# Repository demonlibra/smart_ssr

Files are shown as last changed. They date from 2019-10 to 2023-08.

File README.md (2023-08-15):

# Умное твердотельное реле с анализом ШИМ

### Ссылки
- [Обсуждение в теме форума UNI](https://forum.uni-3d.ru/viewtopic.php?t=527)
- [Как залить Sketch в Arduino?](https://alexgyver.ru/arduino-first)

### Описание проблемы
Твердотельное реле Zero-Cross в процессе работы пропустит только те полупериоды синусоидального напряжения питания, начало которых совпадёт с импульсами сигнала ШИМ от платы управления. В результате твердотельное реле может находится в трёх состояниях: закрыто, открыто и открыто для одного полупериода. Так как между сетевым напряжением и управляющим сигналом ШИМ всегда будет "плавающая" рассинхронизация, можно говорить лишь о вероятности одного из этих состояний.

Например, при частоте питающего напряжения равной частоте ШИМ сигнала управления (50 Гц) и коэффициенте заполнения сигнала управления отличным от 1.0, можно говорить лишь о вероятности одного из трех состояний твердотельного реле.
- Коэффициент заполнения = 1.0 - полная мощность
- Коэффициент заполнения ≥ 0.5 - половина или полная мощность
- Коэффициент заполнения < 0.5 - 0 или половина мощности

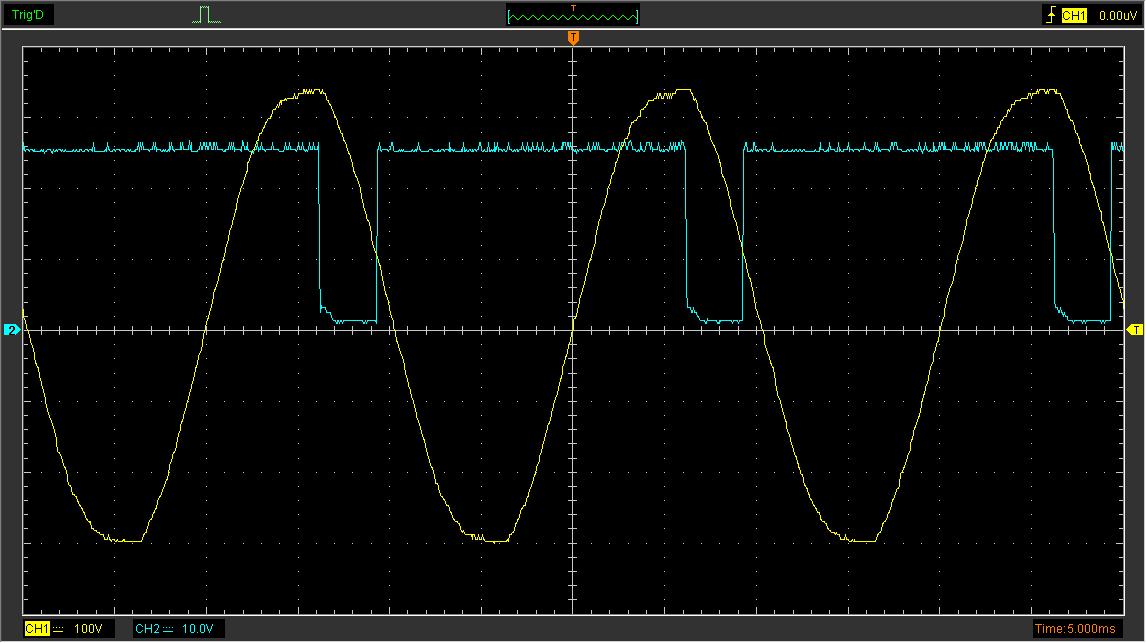
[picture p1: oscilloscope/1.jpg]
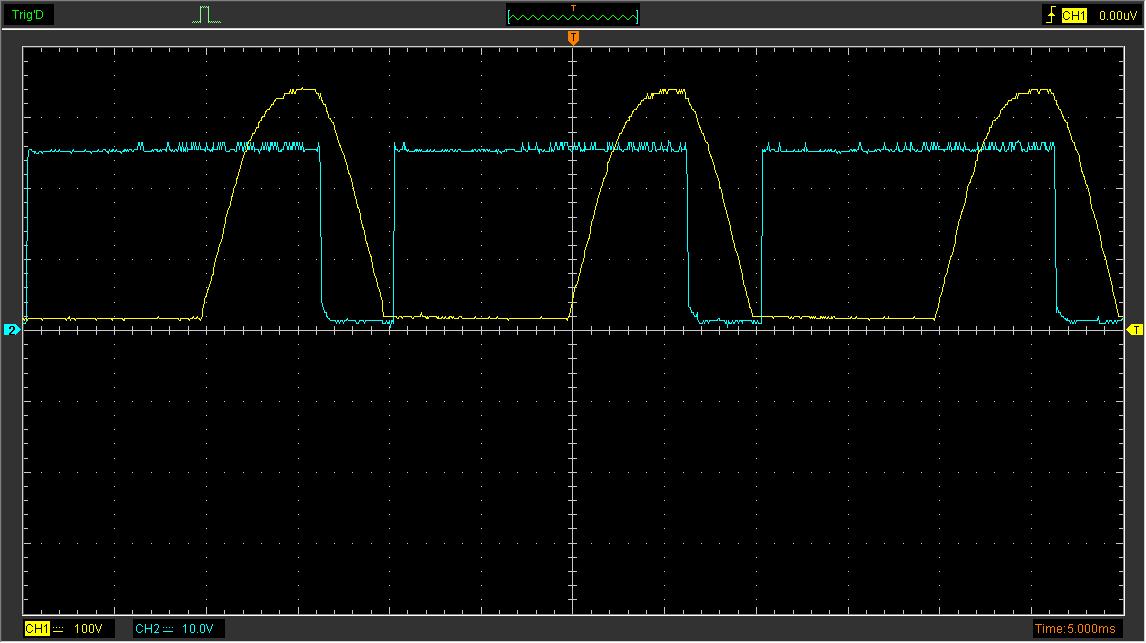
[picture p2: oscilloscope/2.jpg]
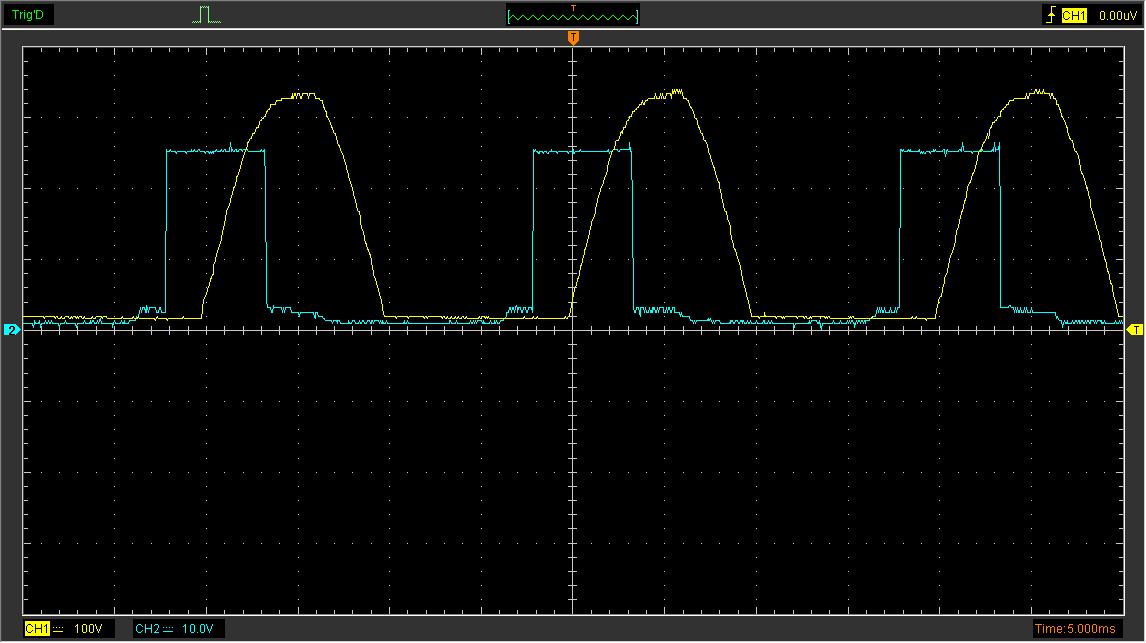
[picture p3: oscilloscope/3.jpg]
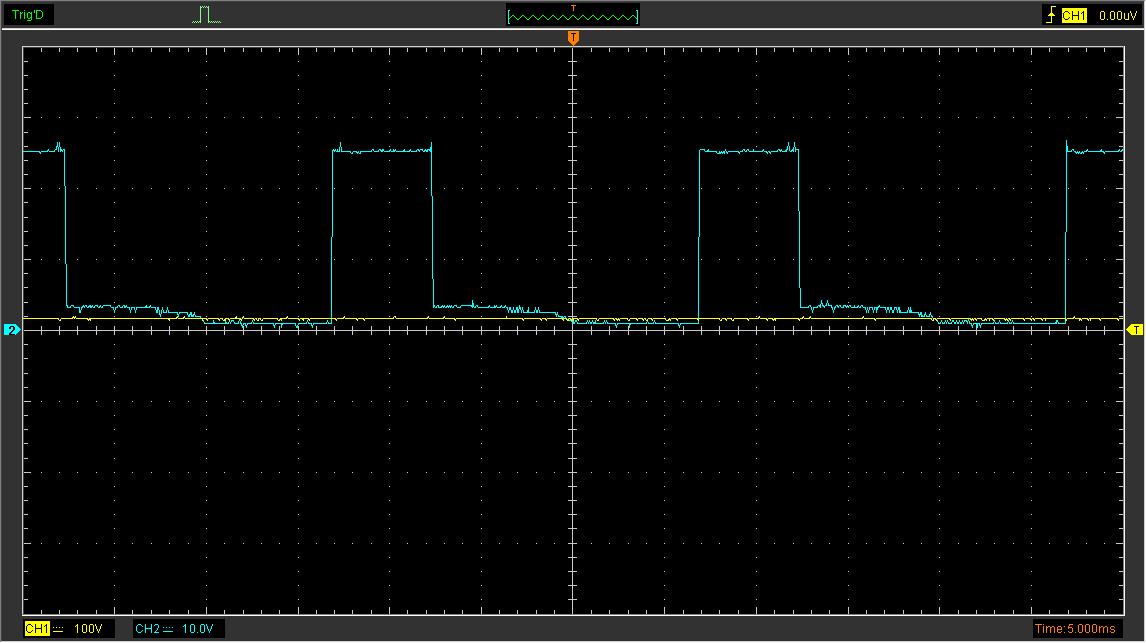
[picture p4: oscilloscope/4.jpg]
   

Снимки 1 и 2 - Коэффициент заполнения ШИМ управляющего сигнала (синий) одинаковый, но мощность на выходе (жёлтый) будет отличаться в два раза.  
Снимки 2 и 3 - Коэффициент заполнения отличается в 4 раза, но мощность одинаковая.  
Снимки 3 и 4 - Коэффициент заполнения одинаковый, но мощность разная.  

Несоответствие коэффициента заполнения ШИМ сигнала управления и выходной мощности может быть причиной больших отклонений температуры от заданной. 
Решить описанную проблему может следующее решение:

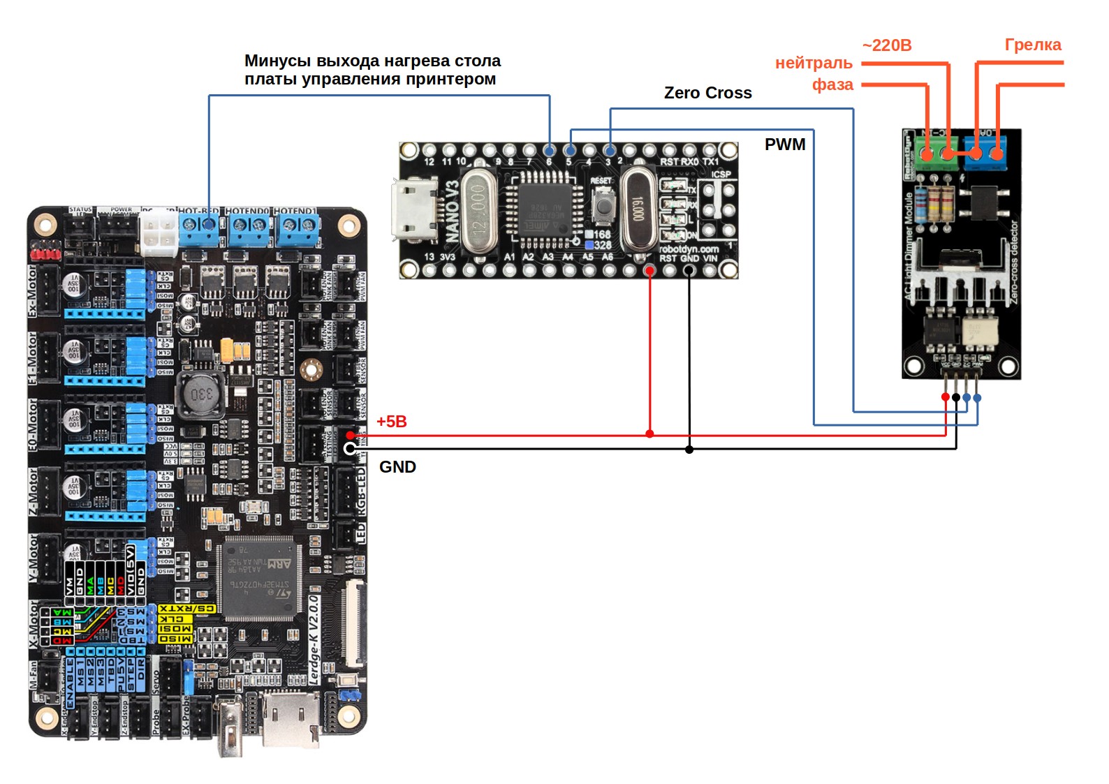
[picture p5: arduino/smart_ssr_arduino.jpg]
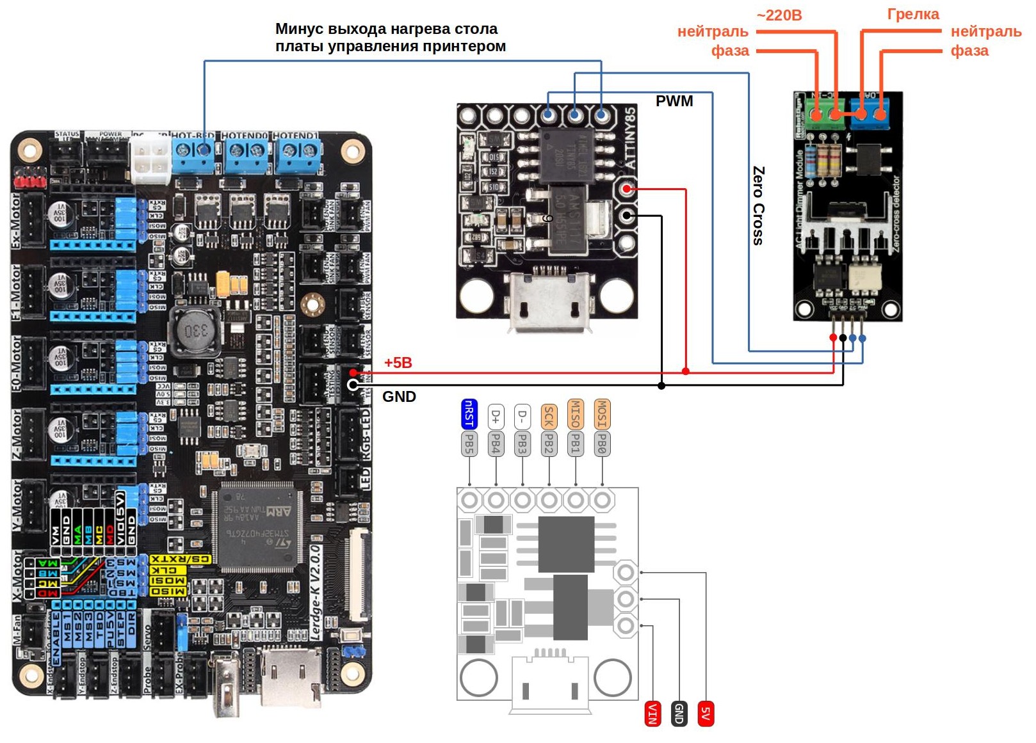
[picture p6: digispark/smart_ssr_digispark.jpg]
 

### Комплектующие
- Arduino или digispark
- [Димер от Robotdyn](https://robotdyn.aliexpress.ru/store/1950989/search?origin=n&SortType=new_desc&SearchText=dimmer)

### Принцип работы
1. Сигнал управления поступает на вход Arduino, которая определяет длительность импульсов включения и коэффициент заполнения ШИМ.
2. Димер подаёт на Arduino сигналы перехода синусоиды напряжения через 0 для определения моментов времени открытия симистора. Таким образом достигается синхронизация сигнала управления и сетевого напряжения.
3. Сетевое напряжение с частотой 50 Гц имеет 100 полупериодов за одну секунду. Arduino выдаёт сигналы управления на димер для получения необходимой мощности, пропуская в единицу времени часть полупериодов сетевого напряжения. Таким образом достигается дискретность задания мощности 1%. Например, если за секунду пропустить только 20 полупериодов, будет получено 20% мощности.

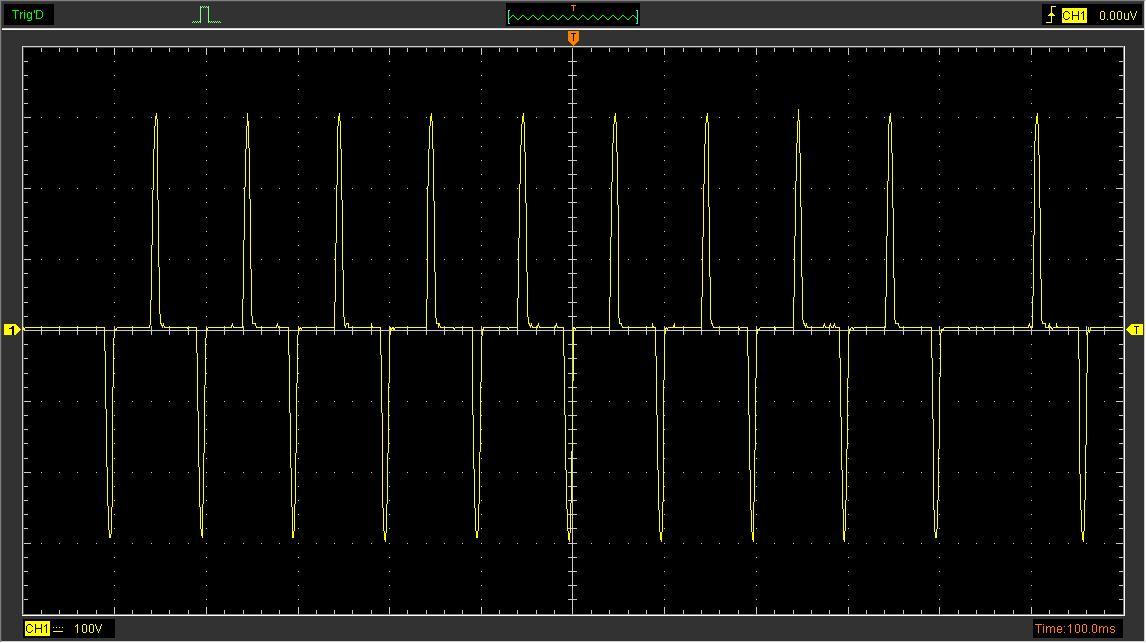
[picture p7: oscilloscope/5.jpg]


Данное решение позволяет устранить проблемы неадекватной работы нагревателя с обычным твердотельным реле:
- Устранить проблему невозможности автоматической калибровки параметров ПИД.
- Обеспечить более точное поддержание температуры.
- Задать ограничение мощности. Может быть актуально для мощных грелок, если стол искривляется от быстрого нагрева.

### Важно
У большинства всё работает и без этого велосипеда. Не торопитесь реализовывать данную схему.
В большинстве случаев проблема управления твердотельным реле решается понижением частоты ШИМ меньше 10 Гц.

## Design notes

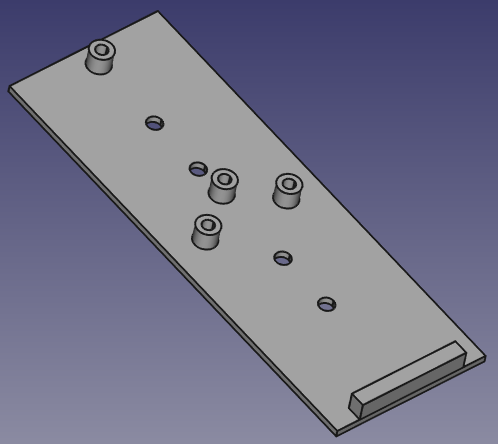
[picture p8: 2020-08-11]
arduino/smart_ssr_arduino.png

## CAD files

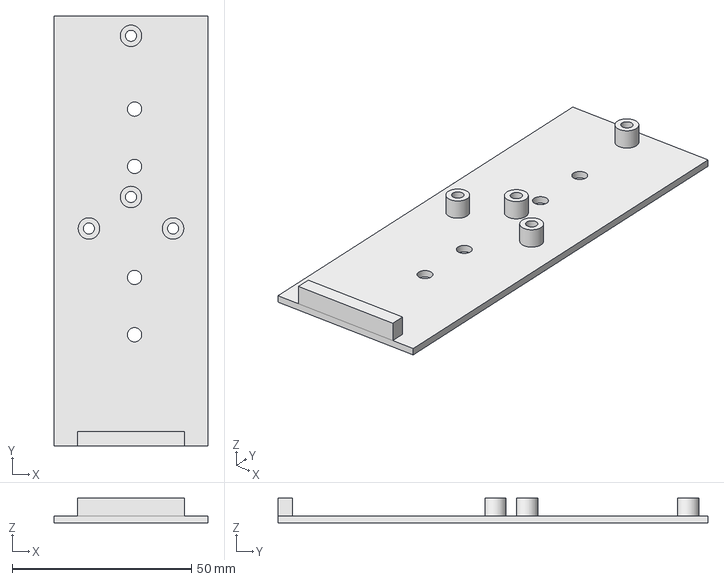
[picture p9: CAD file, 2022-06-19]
arduino/smart_ssr_arduino.step
43.0 x 120.0 x 6.85 mm

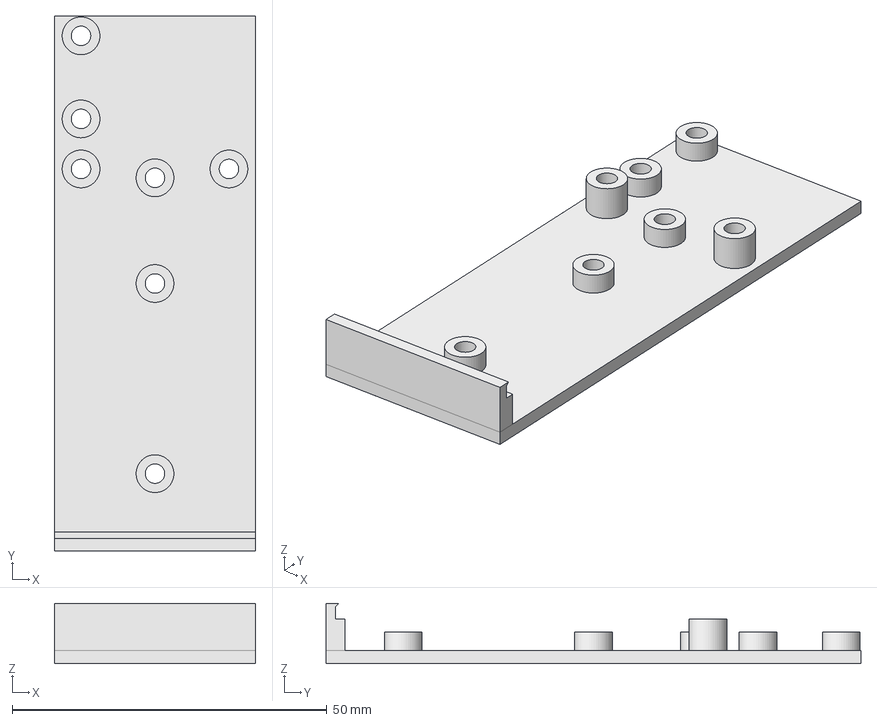
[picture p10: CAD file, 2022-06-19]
digispark/smart_ssr_digispark.step
32.0 x 85.0 x 9.55 mm

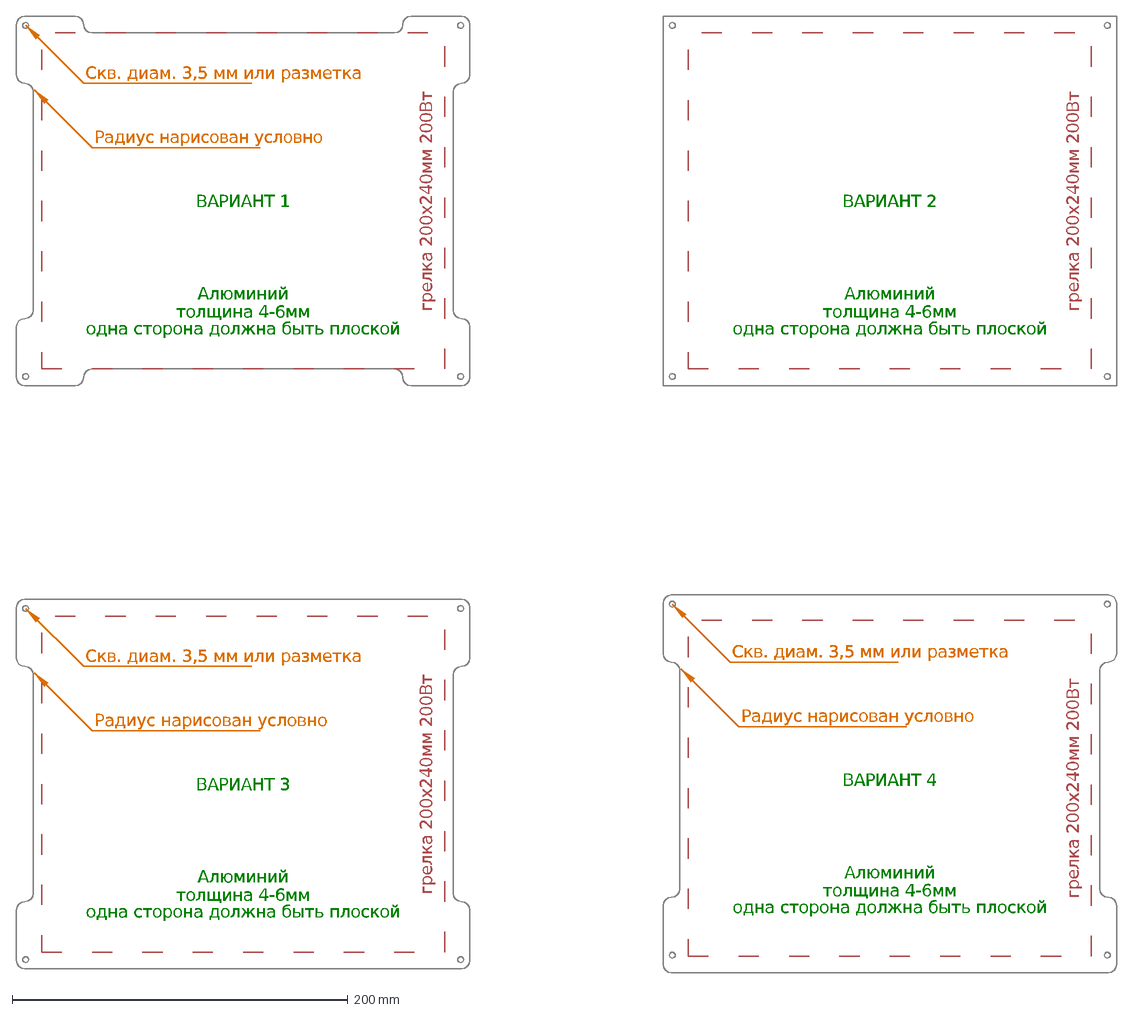
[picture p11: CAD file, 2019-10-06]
Плита стола 220x270.dxf
Cкв. диам. 3,5 мм или разметка
Скв. диам. 3,5 мм или разметка
Радиус нарисован условно
грелка 200х240мм 200Вт
Алюминий
толщина 4-6мм
одна сторона должна быть плоской
ВАРИАНТ 1
ВАРИАНТ 2
ВАРИАНТ 3
ВАРИАНТ 4

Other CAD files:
arduino/dimmer+arduino.step
arduino/smart_ssr_arduino.FCStd
arduino/smart_ssr_arduino.stl
digispark/smart_ssr_digispark.FCStd
digispark/smart_ssr_digispark.stl

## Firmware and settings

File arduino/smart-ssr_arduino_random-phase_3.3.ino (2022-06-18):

// Умное твердотельное реле или Питание грелки без потери ШИМ
// Версия 3.3 для Arduino от 14/08/2020
// Вариант Random-Phase 
// http://uni3d.store/viewtopic.php?f=63&t=527
// https://github.com/demonlibra/uni/tree/master/smart_ssr


// ------------------ Проверьте параметры ниже ---------------------------------------------------------

unsigned int power_nominal = 600;     // Номинальная мощность грелки (Вт)
unsigned int power_limit   = 300;     // Ограничение максимальной мощности грелки (Вт)

const byte   freq_supply   = 50;      //  Частота напряжения в сети (Гц)
const byte   freq_pwm      = 50;      //  Частота ШИМ на выходе платы управления (Гц). Для Lerdge = 50, для Marlin = 8.

const byte   pwm_in        = 6;       // Вход ШИМ сигнала нагрева стола от платы управления принтером
const byte   ZC_in         = 3;       // Вход сигнала перехода синусоиды напряжения через ноль (Zero Cross)
const byte   dimmer_out    = 5;       // Выход управления димером (PWM)

// ------------------ Проверьте параметры выше ---------------------------------------------------------
// -----------------------------------------------------------------------------------------------------


const unsigned int period_supply = 1 * 1000000 / freq_supply;   // Период (мкс) напряжения в сети
const unsigned int period_pwm    = 1 * 1000000 / freq_pwm;      // Период (мкс) ШИМ сигнала на выходе платы управления

unsigned int T = period_supply / 2;   // Задержка включения симистора

float duty_cycle_limit = (float)power_limit / power_nominal;    // Ограничение мощности

int duty = 0;                         // Длительность импульсов ШИМ от платы управления принтером
float duty_cycle;                     // Коэффициент заполнения ШИМ от платы управления принтером
float radian;

uint32_t Lerdge_PWM_Start = micros(); // Время начала импульса ШИМ от платы управления принтером
uint32_t Lerdge_PWM_End   = micros(); // Время окончание импульса ШИМ от пплаты управления принтером
uint32_t timer_ZC         = micros(); // Время перехода синусоиды напряжения через ноль

unsigned int ZC_duration  = 0;        // Длительность импульса определения перехода синусоиды напряжения через ноль

uint32_t timer_debug      = millis(); // Таймер вывода данных в терминал для отладки

bool Lerdge_PWM_state_Now = 1;
bool Lerdge_PWM_state_Before = 1;
bool ZC_before = 0;
bool ZC_now = 0;
bool pwm_out = 0;

void setup() {
  pinMode(pwm_in, INPUT_PULLUP);
  pinMode(ZC_in, INPUT_PULLUP);
  pinMode(dimmer_out, OUTPUT);
  //Serial.begin(9600);
}

void loop() {

  Lerdge_PWM_state_Now = digitalRead(pwm_in);               // Текущее состояние ШИМ

  if (!Lerdge_PWM_state_Now && Lerdge_PWM_state_Before) {
    Lerdge_PWM_Start = micros();                            // Определение фронта импульса ШИМ сигнала
  }
  if (Lerdge_PWM_state_Now && !Lerdge_PWM_state_Before) {
    Lerdge_PWM_End = micros();                              // Определение спада импульса ШИМ сигнала
    duty = Lerdge_PWM_End - Lerdge_PWM_Start;               // Расчёт длительности импульса ШИМ сигнала
  }

  if (!Lerdge_PWM_state_Now && (micros() - Lerdge_PWM_Start > period_pwm)) duty = period_pwm; // Если нет импульсов и коэффициент заполнения 100%
  if (Lerdge_PWM_state_Now && (micros() - Lerdge_PWM_End > period_pwm)) duty = 0;             // Если нет импульсов и коэффициент заполнения 0%
  if (duty < 0) duty = 0;

  duty_cycle = (float)duty / period_pwm;                    // Rоэффициент заполнения ШИМ = Длительность импульса / период (20000 мкс)
  if (duty_cycle > duty_cycle_limit) duty_cycle = duty_cycle_limit;   // Ограничение мощности

  Lerdge_PWM_state_Before = Lerdge_PWM_state_Now;           // Сохранение предыдущего состояния ШИМ


  // Расчет момента времени открытия симистора через пропорцию площади ШИМ и площади синусоиды:
  // ------------------------------------------------------------------------------------------
  //
  // Площадь полупериода синусоиды = 2
  // Необходимая площадь S = (Площадь полупериода синусоиды) х (Коэффициент заполнения) = duty_cycle x 2
  //
  // Площадь под аркой синусоиды S = cos(x1) - cos(x2)
  // Конец арки синусоиды совпадает с переходом через 0, т.е. x2 = Pi и cos(x2) = cos(Pi) = -1
  //
  // duty_cycle x 2 = cos(x1) - (-1)
  // cos(x1) = duty_cycle x 2 - 1
  // radian = acos(duty_cycle * 2 - 1);                         // !!! Вычисление занимает около ~270 мкс
  //
  // Pi     <=> 10000 мс
  // radian <=> T
  //
  // T = radian * period/2 / 3.1415;                              // Момент времени открытия симистора


  ZC_now = digitalRead(ZC_in);                                  // Текущее состояние триггера перехода напряжения через ноль

  if (ZC_now && !ZC_before) {                                   // Выполнять, если обнаружен фронт перехода напряжения через ноль
    pwm_out = 1;                                                // Триггер разрешения выдачи импульса открытия симистора
    timer_ZC = micros();                                        // Запись времени перехода напряжения через ноль
    radian = acos(duty_cycle * 2 - 1);
    T = radian * period_supply/2 / 3.1415;                      // Момент времени открытия симистора
  }

  if (!ZC_now && ZC_before) ZC_duration = micros() - timer_ZC;  // Расчет длительности импульса определения перехода фазы через ноль

  ZC_before = ZC_now;                                           // Сохранение текущего состояния

  // Активация симистора. Импульс необходимо выключить заблаговременно. Иначе спад импульса может оказаться после момент перехода фазы через ноль.
  if ((micros() - timer_ZC > T + ZC_duration/2) && pwm_out && (T < period_supply/2)) {
    digitalWrite(dimmer_out, HIGH);                             // Фронт импульса открытия симистора
    pwm_out = 0;                                                // Обнуление триггера для обеспечения выдачи короткого импульса
    digitalWrite(dimmer_out, LOW);                              // Спад импульса открытия симистора
  } else {
    digitalWrite(dimmer_out, LOW);                              // Контрольный спад импульса открытия симистора
  }

  // Вывод данных в терминал для отладки
  if (millis() - timer_debug > 1000 ) {
    //Serial.println("duty=" + String(duty) + " duty_cycle=" + String(duty_cycle) + " T=" + String(T));
    //Serial.println(duty_cycle);
    //Serial.println("period_supply=" + String(period_supply) + " period_pwm=" + String(period_pwm));
    timer_debug = millis();
  }
}

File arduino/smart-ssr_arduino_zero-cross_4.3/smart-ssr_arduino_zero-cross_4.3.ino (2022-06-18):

// Умное твердотельное реле (Smart-SSR) или "Питание грелки 220В без потери ШИМ"
// Sketch для Arduino
// Версия 4.3 от 05/09/2020
// Вариант Zero-Cross с равномерным распределением включений симистора
// Обсуждение: http://uni3d.store/viewtopic.php?f=63&t=527
// Файлы проекта: https://github.com/demonlibra/uni/tree/master/smart_ssr


// ------------------ Проверьте параметры ниже ---------------------------------------------------------

const uint16_t power_nominal = 600;   // Номинальная мощность грелки (Вт)
const uint16_t power_limit   = 350;   // Ограничение максимальной мощности грелки (Вт)

const byte   freq_supply   = 50;      //  Частота напряжения в сети (Гц)
const byte   freq_pwm      = 50;      //  Частота ШИМ на выходе платы управления (Гц). Для Lerdge = 50, для Marlin = 8.
const byte   update_pwm    = 1;       //  Периодичность изменения ШИМ на выходе платы управления (раз в секунды). Для Lerdge = 1, для Marlin = ???.

const byte   pwm_in        = 6;       // Вход ШИМ сигнала нагрева стола от платы управления принтером
const byte   ZC_in         = 3;       // Вход сигнала перехода синусоиды напряжения через ноль (Zero Cross)
const byte   dimmer_out    = 5;       // Выход управления димером (PWM)

// ------------------ Проверьте параметры выше ---------------------------------------------------------
// -----------------------------------------------------------------------------------------------------

const byte freq_supply_zc   = freq_supply * 2;                   // Количество полупериодов питающего напряжения
const uint32_t period_pwm   = 1000000 / freq_pwm;                // Период (мкс) ШИМ сигнала на выходе платы управления
const byte duty_cycle_limit = 100 * power_limit / power_nominal; // Ограничение мощности через коэффициент заполнения

uint32_t duty = 0;                    // Длительность импульсов ШИМ от платы управления принтером
byte duty_cycle = 0;                  // Расчётный коэффициент заполнения ШИМ от платы управления принтером

byte duty_cycle_count = 0;            // Счётчик полупериодов, которые нужно открыть
byte zc_count = freq_supply_zc;       // Счётчик переходов через ноль

byte skip = 0;                        // Пропуск полупериодов для равномерного распределения
byte skip_count = 0;                  // Счётчик пропуска полупериодов

uint32_t Lerdge_PWM_Start = micros(); // Время начала импульса ШИМ от платы управления принтером
uint32_t Lerdge_PWM_End   = micros(); // Время окончание импульса ШИМ от пплаты управления принтером
uint32_t timer_debug;                 // Таймер вывода данных в последовательный порт    

bool Lerdge_PWM_state_Now = 1;        // Текущее состояние сигнала ШИМ (сигнал инвертирован)
bool Lerdge_PWM_state_Before = 1;     // Предыдущее состояние сигнала ШИМ (сигнал инвертирован)
bool ZC_now = 0;                      // Текущее состояние сигнала Zero-Cross
bool ZC_before = 0;                   // Предыдущее состояние сигнала Zero-Cross

void setup() {
  pinMode(pwm_in, INPUT_PULLUP);      // Назначение входа для сигнала ШИМ от платы управления
  pinMode(ZC_in, INPUT_PULLUP);       // Назначение входа для сигнала Zero-Cross от димера
  pinMode(dimmer_out, OUTPUT);        // Назначение выхода управления димером

  //Serial.begin(9600);
}

void loop() {

  Lerdge_PWM_state_Now = digitalRead(pwm_in);               // Текущее состояние ШИМ
  
  if (!Lerdge_PWM_state_Now && Lerdge_PWM_state_Before) {
    Lerdge_PWM_Start = micros();                            // Определение фронта импульса ШИМ сигнала
  }
  if (Lerdge_PWM_state_Now && !Lerdge_PWM_state_Before) {
    Lerdge_PWM_End = micros();                              // Определение спада импульса ШИМ сигнала
    duty = Lerdge_PWM_End - Lerdge_PWM_Start;               // Расчёт длительности импульса ШИМ сигнала
  }
  
  if (!Lerdge_PWM_state_Now && (micros() - Lerdge_PWM_Start > period_pwm)) duty = period_pwm; // Если нет импульсов и коэффициент заполнения 100%
  if (Lerdge_PWM_state_Now && (micros() - Lerdge_PWM_End > period_pwm)) duty = 0;             // Если нет импульсов и коэффициент заполнения 0%
  
  duty_cycle = 100 * duty / period_pwm;                               // Rоэффициент заполнения ШИМ = Длительность импульса / период (20000 мкс)
  if (duty_cycle > duty_cycle_limit) duty_cycle = duty_cycle_limit;   // Ограничение мощности

  Lerdge_PWM_state_Before = Lerdge_PWM_state_Now;           // Сохранение предыдущего состояния сигнала ШИМ

  ZC_now = digitalRead(ZC_in);                              // Запись текущего состояния триггера Zero-Cross

  if (!ZC_now && ZC_before) {                               // Обнаружение спада импульса Zero-Cross
    if (zc_count > 0) zc_count -= 1;                        // Пересчет сигналов Zero-Cross в течении одной секунды
    else {
      zc_count = freq_supply_zc;                            // Сброс счётчика пересчёта сигналов Zero-Cross
      duty_cycle_count = duty_cycle;                        // Сколько полупериодов открыть симистор
      skip = (freq_supply_zc / duty_cycle_count) - 1;       // Первичный расчёт пропуска полупериодов для равномерного распределения
      //Serial.println(duty_cycle);
    }
  }
   
  
  // Активация симистора
  if ((!ZC_now && ZC_before) && (duty_cycle_count > 0)) {
    if (skip_count > 0) skip_count -= 1;
    else                skip_count = skip;                  // Сброс счётчика пропуска полупериодов

    if (skip_count == 0) {
      digitalWrite(dimmer_out, HIGH);                       // Фронт импульса открытия симистора
      digitalWrite(dimmer_out, LOW);                        // Спад импульса открытия симистора
      duty_cycle_count -= 1;                                // Сколько осталось выполнить открытий симистора

      // Остаток количества возможных моментов включения делится на остаток необходимых включений
      // Если > 1, т.е. 2, то значение первичного пропуска увеличивается на 1
      if ((((freq_supply_zc - zc_count) / duty_cycle_count) > 1) && (skip == 0)) skip += 1;
    } 
  }
  ZC_before = ZC_now;                                       // Сохранение текущего состояния сигнала Zero-Cross

}

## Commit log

2019-10-06 initial project version
    [Плита стола 220x270.dxf]
2019-10-07 Add table 300x200
    [table_plate.dxf]
2019-10-07 Add some comments
    [table_plate.dxf]
2019-10-11 Some fixes homing.sh
2019-10-19 Some fixes. Add M84 (Set motor disable timeout). Add check present /dev/ttyUSBx.
2019-10-29 Add script backlash Z for CURA
2019-10-30 Backlash Z - Added comments
2019-11-01 Cura - Added backlashZ_first_layer
2019-11-30 Some changes in table_plate.dxf
    [table_plate.dxf]
2019-12-29 Added README.md to folder 'power'
2020-01-02 Added models to install direct BMG
    [Direct_BMG_E3DV6_Rev3.FCStd]
2020-01-02 Changes in Direct 3d models
    [Direct_BMG_E3DV6_Rev3.FCStd]
2020-01-04 Added adapter for 4010 fan in model
2020-01-15 retract_calibration_towers.sh - Added commits and Some fixes
    [retract_calibration_towers.stl]
2020-01-16 Added script for CURA - retract_calibration_towers
    [retract_calibration_towers.stl]
2020-01-17 retract_calibration_towers.sh - Added cut gcode and commits
2020-01-18 New folder for plate dxf
    [table_plate.dxf]
2020-01-21 Power - Added checking connection Lerdge with OctoPrint
2020-01-21 Power - Add stl model and sorting
    [pad_ssr_relay.FCStd, pad_ssr_relay.stl]
2020-01-22 Added models for chain
    [table_down.FCStd, table_down.stl, top_wall_35mm.FCStd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]
2020-01-22 Added models of cable holders
    [cable_holder_2.FCStd, cable_holder_2.stl, cable_holder_3x.FCStd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]
2020-02-01 Added model to install FAN 120 mm over Lerdge-K
    [LerdgeK-Plate_for_FAN120mm.FCStd, LerdgeK-Plate_for_FAN120mm.stl]
2020-02-23 Direct - Release 2
    [Assembly.FCStd, BLK_Holder.FCStd, X_CAM.FCStd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]
2020-02-28 Direct - Screws
2020-03-07 Added models for top cover
    [models.FCStd]
2020-03-09 Top cover - Little fixes
    [models.FCStd]
2020-03-14 Added model - filament_holder_rear
    [filament_holder_rear.FCStd, filament_holder_rear.step, filament_holder_rear.stl]
2020-03-16 Added models - Foots
    [foots.FCStd, foots.step, front_left.stl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]
2020-03-17 Added model - cable_holder_2_backside
    [cable_holder_2_backside.FCStd, cable_holder_2_backside.stl]
2020-03-18 Some fixes
    [retract_calibration_towers.stl]
2020-05-24 Direct Rev3
    [Assembly.FCStd, BLK_Holder.FCStd, Rev3.FCStd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]
2020-05-26 top_cover - stl and step
    [front1.stl, front2.stl, models.step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]
2020-06-28 Direct 3.2
    [Rev3.2.FCStd, Rev3.FCStd, Rev3.step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]
2020-07-08 CURA - break_heating_hotbed - Added start_temp and some fixes
    [base.step, belt_fix.step, bltouch_holder.step]
2020-08-10 Added Smart SSR
    [pwm_control.FCStd, pwm_control.step, pwm_control.stl]
2020-08-11 Smart SSR - Some fixes
    [pwm_control_v2.FCStd, pwm_control_v2.step, pwm_control_v2.stl]
2020-08-14 Smart SSR 3.3 - Some fixes
    [dimmer+arduino+opto+lm317.FCStd, dimmer+arduino+opto+lm317.step, dimmer+arduino+opto+lm317.stl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]
2020-09-02 Added project digispark
    [dimmer+arduino+opto+lm317.FCStd, dimmer+arduino+opto+lm317.step, dimmer+arduino+opto+lm317.stl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]
2020-09-04 Smart SSR- Some fixes
    [sketch_arduino_3.3.ino, sketch_arduino_4.2.ino]
2020-11-26 Some fixes in Smart SSR
    [smart-ssr_arduino_random-phase_3.3.ino, smart-ssr_arduino_zero-cross_4.3.ino, smart-ssr_digispark_random-phase_3.4.ino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]
2022-06-18 separate project
    [LerdgeK-Plate_for_FAN120mm.FCStd, LerdgeK-Plate_for_FAN120mm.stl, Rev3.2.FCStd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]
2022-06-19 rename files
    [dimmer+arduino+opto+lm317.FCStd, dimmer+arduino+opto+lm317.step, dimmer+arduino+opto+lm317.stl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]
2023-08-15 смена адреса форума на forum.uni-3d.ru
